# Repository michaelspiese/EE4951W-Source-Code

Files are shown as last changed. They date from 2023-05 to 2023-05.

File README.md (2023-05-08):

# SoccerTracker: Method for Tracking and Photographing a Soccer Player

## Motive

If one wished to photograph a soccer player and take "action shots" while they were playing the game, most of their focus would be on making sure the photos turned out and not on the game itself. This project aims to solve this problem by automating the camera's position, focus, and magnification; reducing the user's role in taking photos to providing an input of when the photos should be taken.

## Method

An Ultra-Wideband sensor network is used to track the player. Three anchors are set an static positions on the field, and the tag calculates its xyz-position based on it's distance from the anchors. A fifth sensor is used as a passive anchor gateway node, to which the tag can directly send its position. The gateway node is connected to a Raspberry Pi Model 3B via the gpio pins, and UART is used to send and receive data between the Pi and gateway. From the position of the tag, the angle and distance from the camera at the origin to the tag can be calculated and used to control other systems. The loop in `main.py` runs forever and exists to update the position recognized by the program as fast as data is sent from the sensor.

The angle of the camera is controlled by a servo in a separate daemon thread from the main thread that is updating the position. This servo simply takes the angle to the tag, writes it to the Pi's PWM pin, and delays for 0.1 seconds (the speed data is written from the sensor).

The camera shutter button is a bluetooth button. In yet another daemon thread, the program waits for the button to connect and then polls all events from the button for presses in a loop that runs forever. Whenever a press is detected, an integer "queue" is incremented signaling that a picture should be taken.

The camera is implemented in one final daemon thread that is separate from the main thread. First, the queue from the button must be greater than 0. If there is a camera event expected, the camera simply reads the distance to the tag, updates the camera settings to the required focus and magnification, saves a picture, and decrements the queue.

With more time/resources, there are a few ways to expand on the functionality of this system in the future. First, we would like to create a more robust sensor network for more accurate positional data. Also, using the cloud to be able to access the pictures that were taken remotely would remove the need for the user to retrieve these photos themselves.

This program is configured to run when the Raspberry Pi boots. The section "Configuring the Raspberry Pi" section below details how this is done and also how to install the necessary dependencies.

## Hardware

Tracking: DWM1001-Dev x 5

Camera: ArduCam Hawk Eye 64MP

Camera movement: SG90 Servo

Camera button: AB Shutter 3

Microcontroller: Raspberry Pi Model 3B

# Configuring the Raspberry Pi

## Installing Dependencies

Before running the program, the python modules `pigpio`, `evdev`, and proprietary flavors of `libcamera` and `picamera2` must be installed. 

### Installing python modules from apt

Below is the commands to install `pigpio` and `evdev`:

```shell
> sudo apt update
> sudo apt upgrage
> sudo apt-get install pigpio
> sudo apt-get install python3-evdev
```

### Installing ArduCam modules and drivers

`Libcamera` and `picamera2` are installed by default on newer builds of Raspbian. However, ArduCam has their own proprietary flavors of these programs that must be installed before the ArduCam Hawk Eye camera can be used.

```shell
> sudo wget -O install_pivariety_pkgs.sh https://github.com/ArduCAM/Arducam-Pivariety-V4L2-Driver/releases/download/install_script/install_pivariety_pkgs.sh
> sudo chmod +x install_pivariety_pkgs.sh
> ./install_pivariety_pkgs.sh -p libcamera
> ./install_pivariety_pkgs.sh -p libcamera_apps
> ./install_pivariety_pkgs.sh -p 64mp_pi_hawk_eye_kernel_driver
```

It is also necessary to add the following lines to `/boot/config.txt` under [All]:

```
dtoverlay=arducam-64mp
dtoverlay=vc4-kms-v3d,cma-512
```

## Boot script

In order to make the device more user-friendly, a script to launch the program at boot should be created. In our case, the boot script `soccer-tracker.sh` looks like the following:

```shell
#!/bin/bash
sudo pigpiod &
sleep 10
lxterminal --title="Soccer Tracker" -e "python3 /home/ee4951w/src/main.py; read -n 1 -s" 
```

Make sure to change the location to the main python file, and add this script to the directory `/usr/local/bin`.

Next, use the following command to make this shell file an executable script:

```bash
> sudo chmod +x /usr/local/bin/soccer-tracker.sh
```

## Autostart

Since this project runs at startup in a terminal window, we are using LXDE-pi autostart to run our boot script after the graphical environment has been started. Add the following line to the end of the file `/etc/xdg/lxsession/LXDE-pi/autostart` for the same results.

```
@bash /path-to-boot-script/soccer-tracker.sh
```

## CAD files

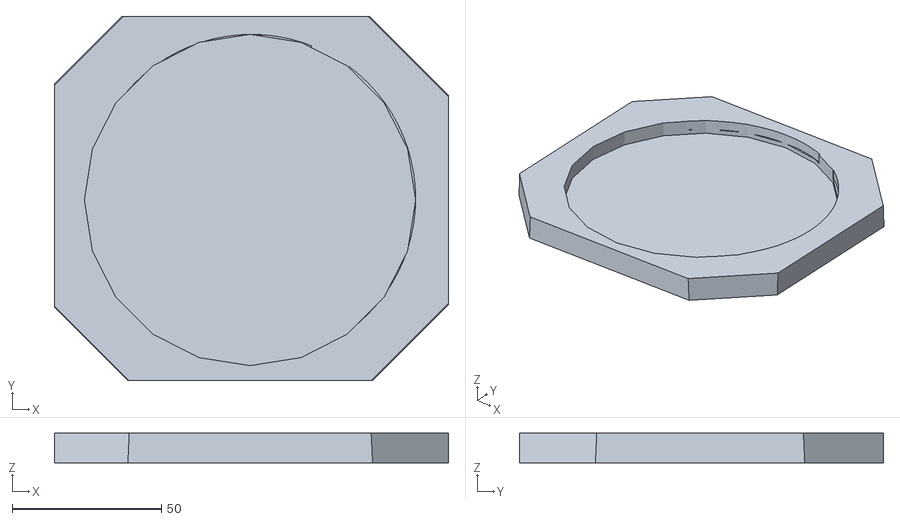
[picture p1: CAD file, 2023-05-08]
3D Parts/Tripod hub.stl
132.0 x 122.0 x 10.0

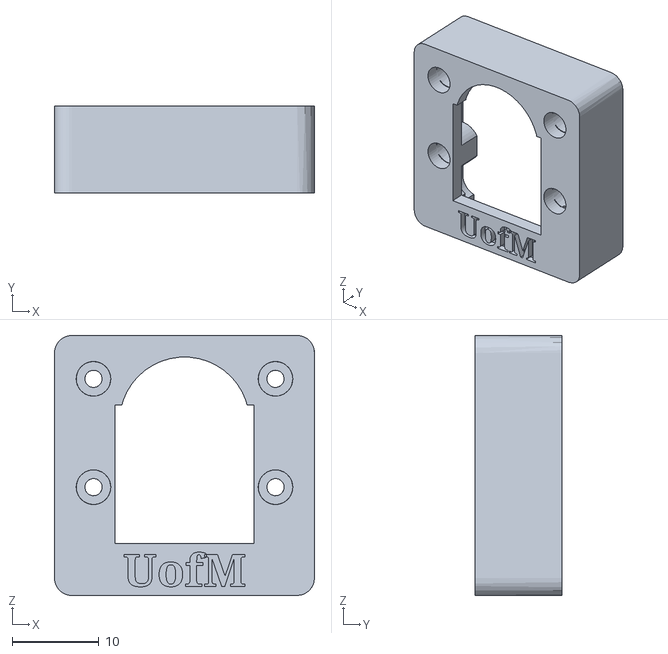
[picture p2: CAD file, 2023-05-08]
3D Parts/Camera cover.stl
30.0 x 10.0 x 30.0

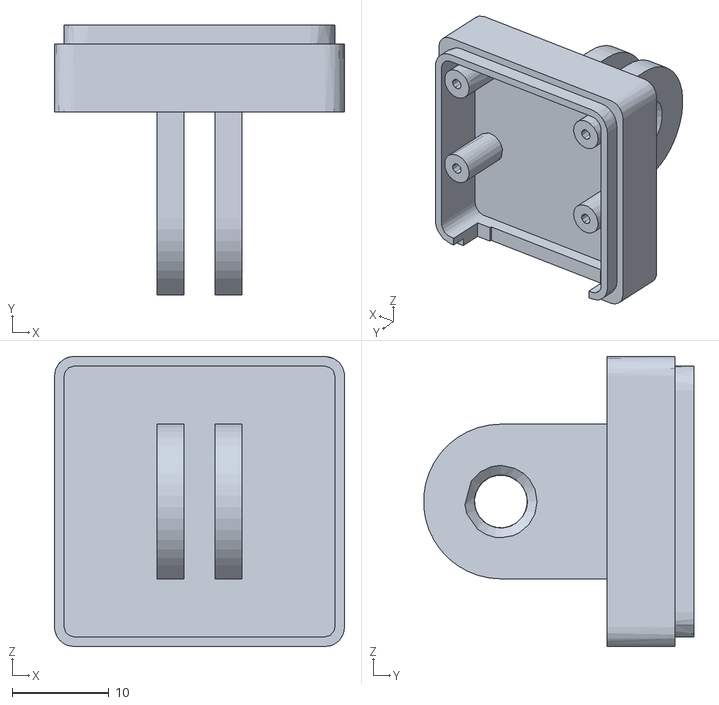
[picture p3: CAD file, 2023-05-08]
3D Parts/Camera case.stl
30.0 x 28.0 x 30.0

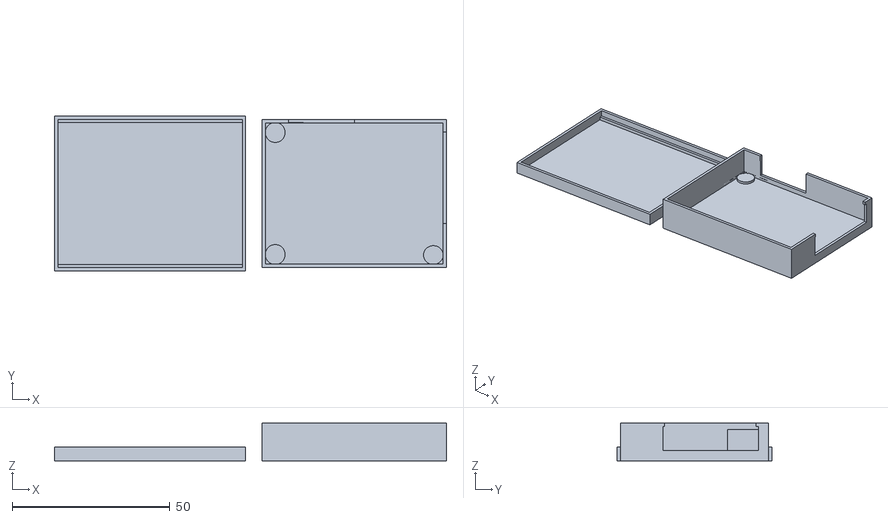
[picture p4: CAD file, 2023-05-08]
3D Parts/Sensors case.stl
124.2 x 49.0 x 12.0

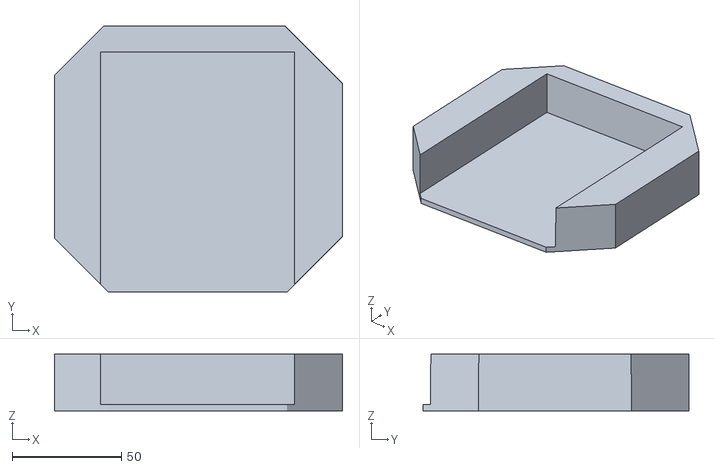
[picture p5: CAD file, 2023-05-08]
3D Parts/powerBank.stl
132.0 x 122.0 x 26.0

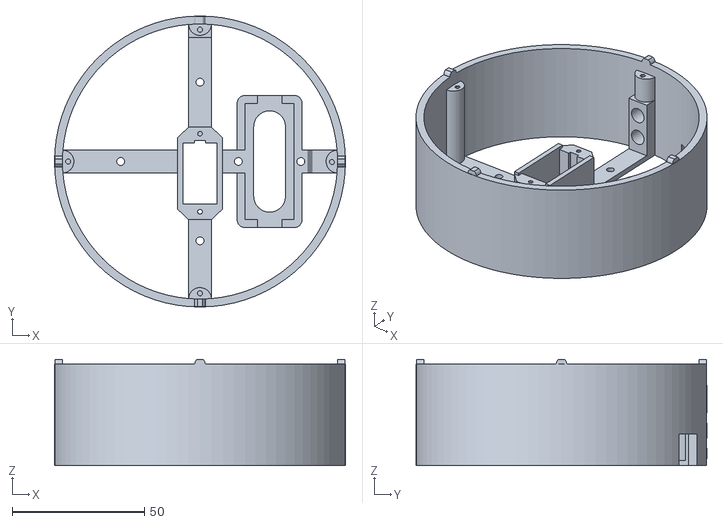
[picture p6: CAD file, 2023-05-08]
3D Parts/rotating-part-base.obj
110.0 x 110.0 x 40.2

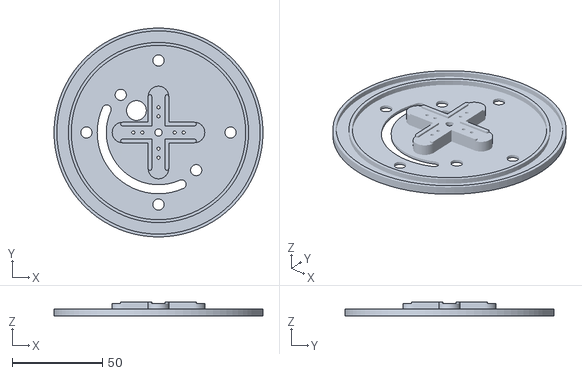
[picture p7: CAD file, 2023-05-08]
3D Parts/rotating-part-top.obj
116.0 x 116.0 x 8.02

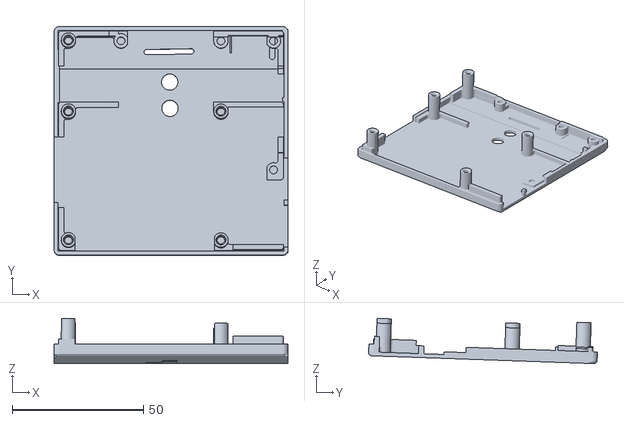
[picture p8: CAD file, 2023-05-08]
3D Parts/Rasbpberry-pi-enclosure-cap.obj
89.0 x 87.1 x 17.2

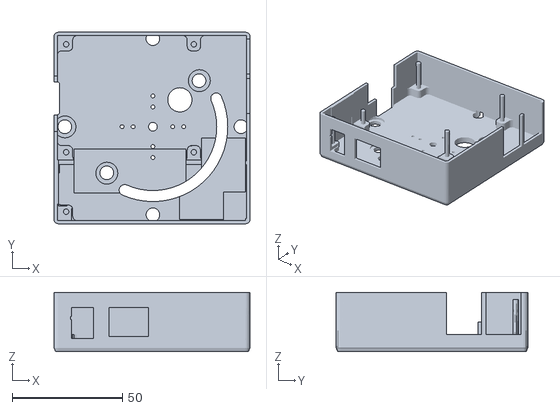
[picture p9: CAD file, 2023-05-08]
3D Parts/Raspberry-pi-enclosure.obj
89.0 x 87.0 x 27.0

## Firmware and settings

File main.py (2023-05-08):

import UWB, servo, cam, shutter, time, threading

# Thread to move servo to angle of tag
def servoThread():
    while True:
        serv.move(uwb.theta)
        time.sleep(0.1)
        
# Thread to take a photo when the shutter button is pressed
def cameraThread():
    while True:
        time.sleep(0.5)
        if btn.queue > 0:
            camera.takePhoto()
            print(f"Removing camera event from queue ({btn.queue-1} total)")
            btn.queue -= 1

# Setup function to initialize all sensors, devices, and threads
def setup():
    global serv, uwb, camera, btn
    
    uwb = UWB.UWB("/dev/ttyACM0", 1)                # Open serial connection to gateway with USB port /dev/ttyACM0
    serv = servo.Servo(12)                          # Initialize servo on GPIO pin 12
    btn = shutter.Shutter()                         # Initialize shutter button
    camera = cam.ArducamHawkEye(res=(2312, 1736))   # Initialize camera with resolution 2312x1736
    
    # Start threads for each asynchronous task
    threading.Thread(target=servoThread, daemon=True).start()
    threading.Thread(target=btn.btn_loop, daemon=True).start()
    threading.Thread(target=cameraThread, daemon=True).start()

# Cleanup function to safely exit program
def cleanup():
    uwb.close()
    serv.stop_pwm()

# Main function to run program. Setup -> Run -> Cleanup
if __name__ == "__main__":
    setup()

    uwb.toggleDataFlow()
    while 1:
        # Update position of tag as fast as possible until keyboard interrupt is received.
        try:
            uwb.update_pos()
        except Exception as ex:
            print(ex)
            break
        except KeyboardInterrupt:
            break
    
    # Cleanup and exit
    cleanup()

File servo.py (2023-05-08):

import pigpio, time

class Servo:
	def __init__(self, pin):
		# Initializing servo on GPIO pin specified in main's setup function
		self.pin = pin
		self.pwm = pigpio.pi()
		self.pwm.set_mode(self.pin, pigpio.OUTPUT)
		self.pwm.set_PWM_frequency(self.pin, 50)
		
	# Function to move servo to specified angle
	# Updating duty cycle written to servo to range of 500 - 2500 (pigpio specification for 0 - 180 degrees)
	def move(self, angle):
		dc = (angle / 180) * 2000 + 500  
		self.pwm.set_servo_pulsewidth(self.pin, dc)
	
	# Function to stop sending PWM signal to servo. Disengages servo.
	def stop_pwm(self):
		self.pwm.set_PWM_dutycycle(self.pin, 0)
		self.pwm.set_PWM_frequency(self.pin, 0)

# For testing purposes. Run this file to see if the Servo class works as intended.
# Initializes servo on GPIO pin 12 and moves it to angle specified by user input.
if __name__ == "__main__":
	s = Servo(12)
	while True:
		try:
			angle = int(input("Enter angle (0-180): "))
			s.move(angle) 
		except KeyboardInterrupt:
			break
	s.stop_pwm()

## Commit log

2023-03-26 Changed file name to be more specific, precision lowered due to new sensor config
2023-03-28 Adding simple alternative servo code for reference when cleaning codebase
2023-03-31 Adding camera and shutter control for picture taking. Currently saves to working directory
2023-05-08 Cleaning Repository
    Deprecated code removed, python code cleaned and commented, and a few of the 3D printed parts added to repository.
    [Rasbpberry-pi-enclosure-cap.obj, Raspberry-pi-enclosure.obj, rotating-part-base.obj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]
2023-05-08 Adding Additional 3D parts
    [Camera case.stl, Camera cover.stl, Sensors case.stl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]
